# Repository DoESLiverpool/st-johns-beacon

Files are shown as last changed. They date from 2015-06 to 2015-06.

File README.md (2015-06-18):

A large scale 3D printable model of St John's Beacon (The Radio City Tower) in Liverpool. Intended to be printed on 
an Ultimaker 2 Extended, and take full advantage of the 30cm print height, to give a tower approximately 1m tall. 

Blank faced letter blocks around the circumfrence allow LEDs inside the cupola to light the letters for display from 
an Arduino inside.

 * DoES Liverpool's repo is at: [github.com/DoESLiverpool/st-johns-beacon](https://github.com/DoESLiverpool/st-johns-beacon)
 * Alternative git repo is at: [git.defproc.co.uk/DefProc/st-johns-beacon](https://git.defproc.co.uk/DefProc/st-johns-beacon)
 * Original CAD models are at [cad.onshape.com](https://cad.onshape.com/documents/28927cba45614a8eae7bdee6)

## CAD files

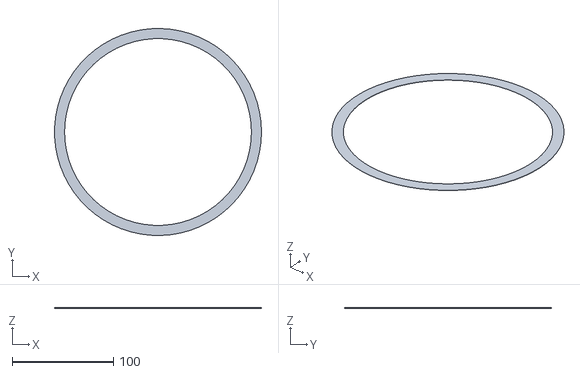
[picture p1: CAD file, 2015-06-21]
large-multi-piece/Letter Ring/RCT - Ring Pattern - bottom.stl
204.9 x 204.8 x 1.00

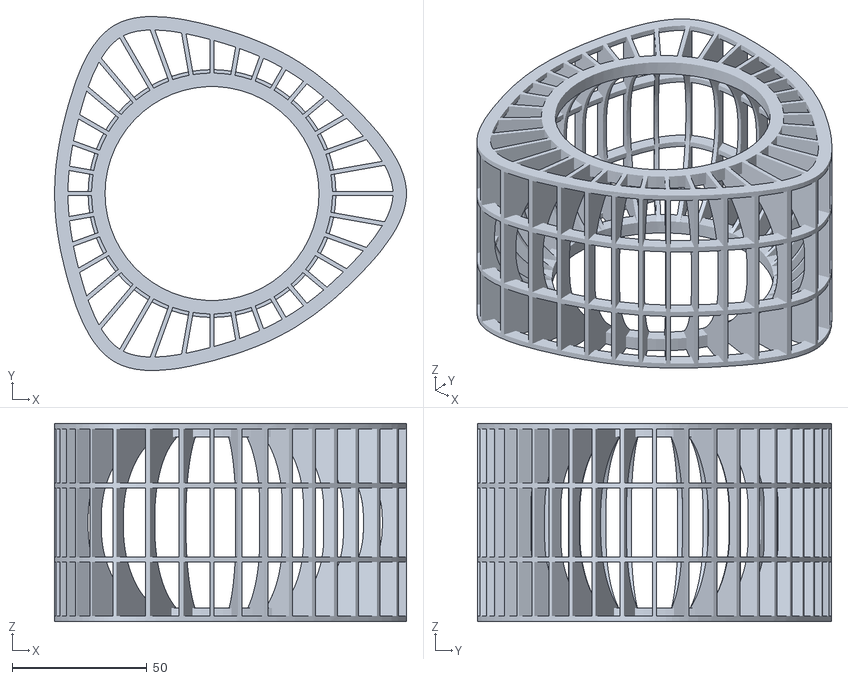
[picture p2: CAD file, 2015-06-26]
large-multi-piece/RCT - Advertising Hoarding.stl
130.7 x 131.4 x 73.5

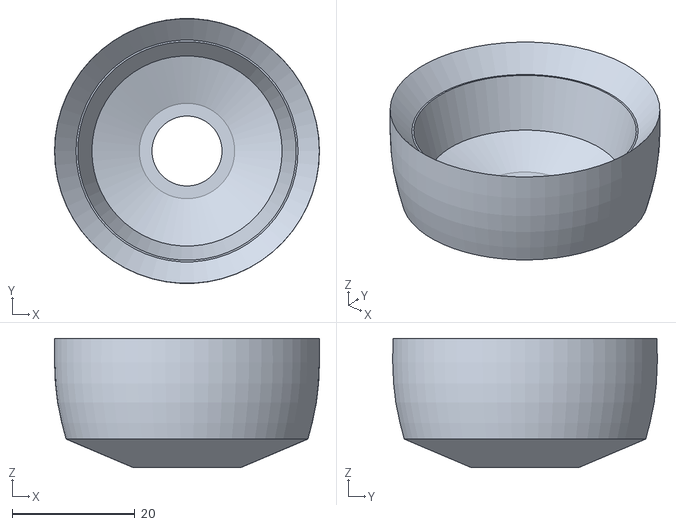
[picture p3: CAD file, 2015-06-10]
small-five-piece/St John's Beacon, Radio City Tower - Cupola.stl
43.1 x 43.1 x 21.0

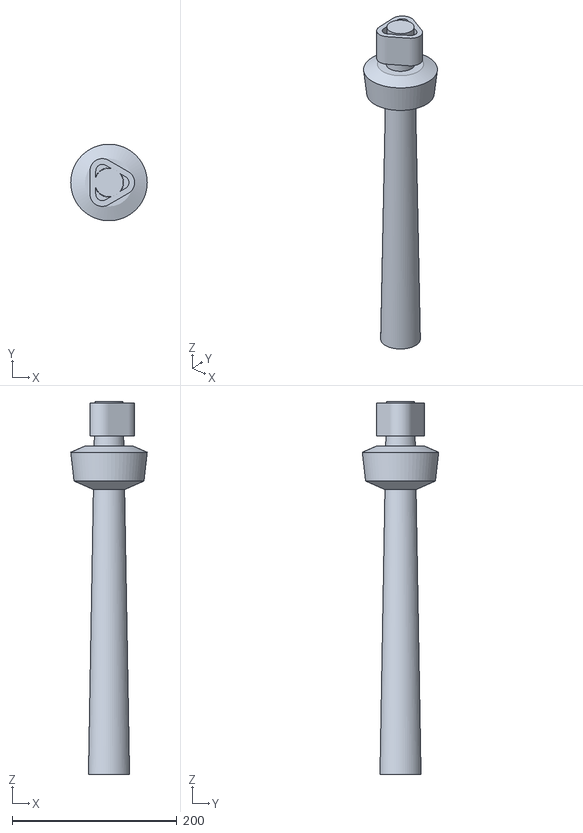
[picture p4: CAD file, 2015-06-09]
small-one-piece/St John's Beacon, Radio City Tower - Single Piece Tower.stl
93.0 x 92.9 x 453.0

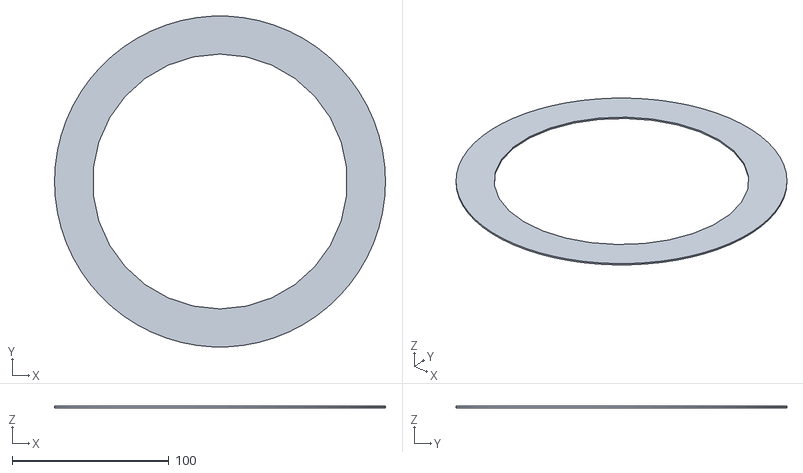
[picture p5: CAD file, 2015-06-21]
large-multi-piece/Letter Ring/RCT - Ring Pattern - top.stl
211.2 x 211.0 x 1.00

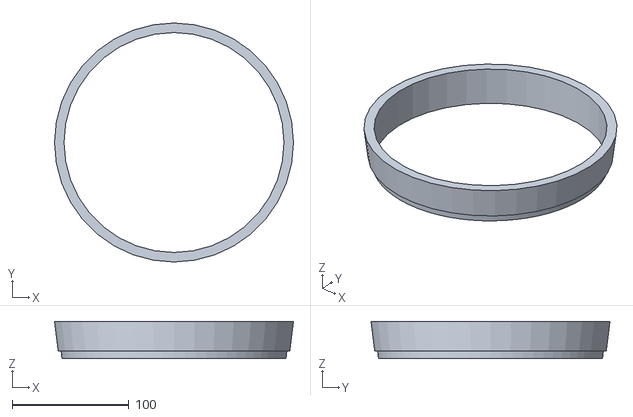
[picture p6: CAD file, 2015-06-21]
large-multi-piece/RCT - Bottom Windows.stl
205.1 x 205.1 x 32.0

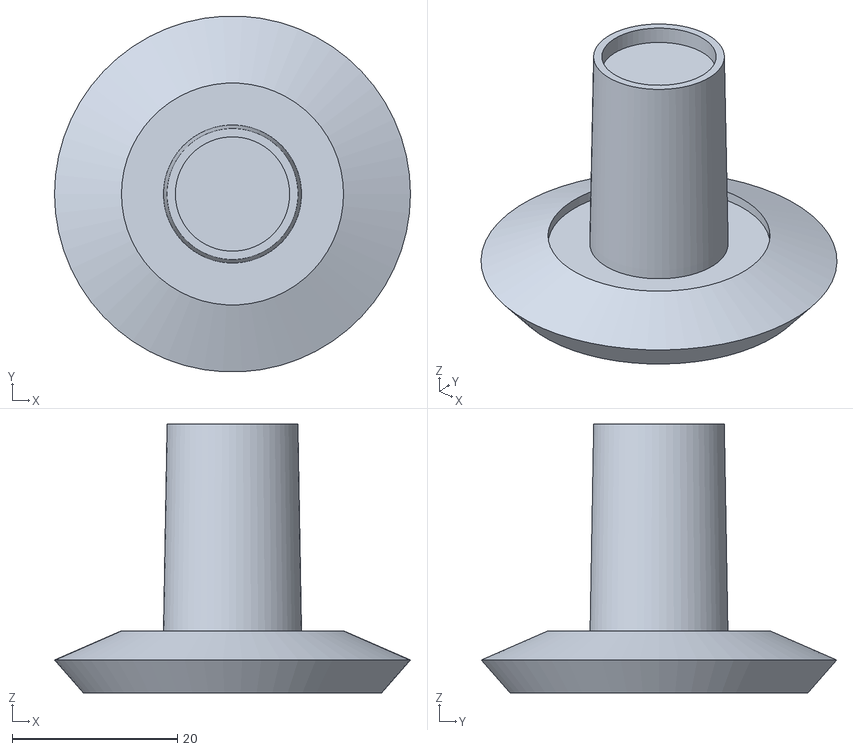
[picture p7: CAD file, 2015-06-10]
small-five-piece/St John's Beacon, Radio City Tower - Spire.stl
43.1 x 43.0 x 32.5

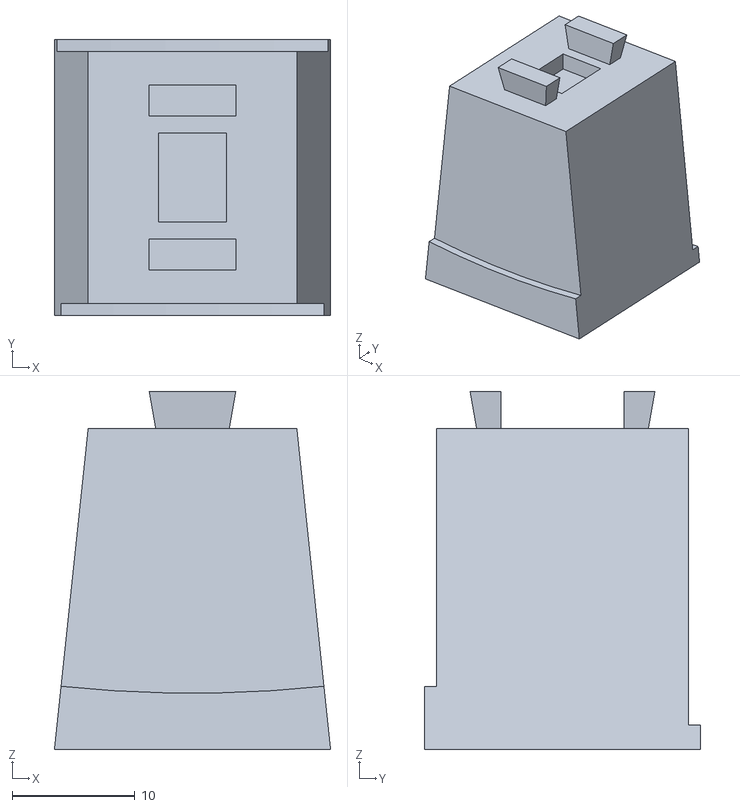
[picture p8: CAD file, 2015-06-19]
large-multi-piece/Letter Ring/RCT - Blank Letter Block.stl
22.5 x 22.5 x 29.2

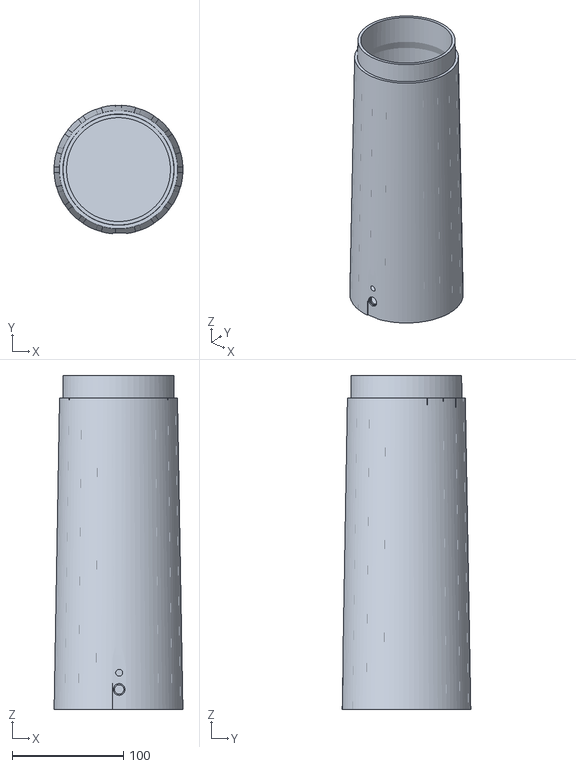
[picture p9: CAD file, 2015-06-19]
large-multi-piece/RCT - Tower Base 1.stl
115.7 x 115.5 x 300.0

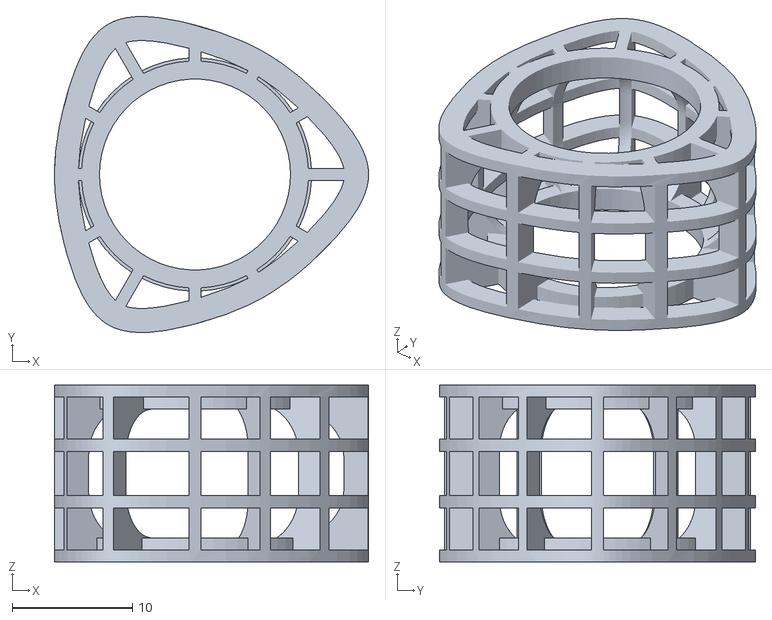
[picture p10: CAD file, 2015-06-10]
small-five-piece/St John's Beacon, Radio City Tower - Advertising Hoarding.stl
26.1 x 26.3 x 14.7

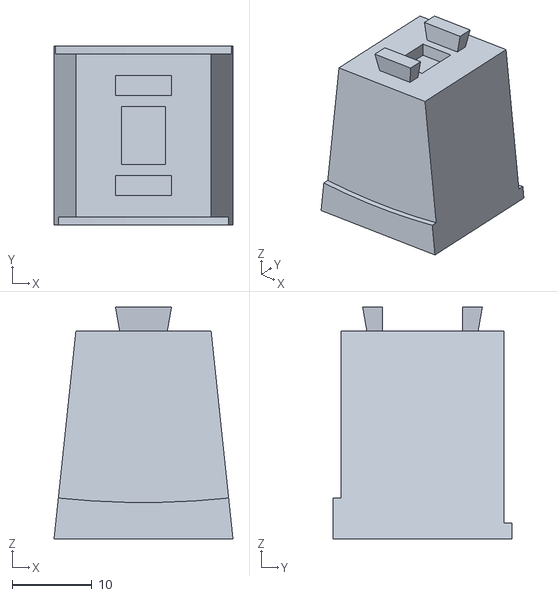
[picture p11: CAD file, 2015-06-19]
large-multi-piece/Letter Ring/letter-L.stl
22.5 x 22.5 x 29.2

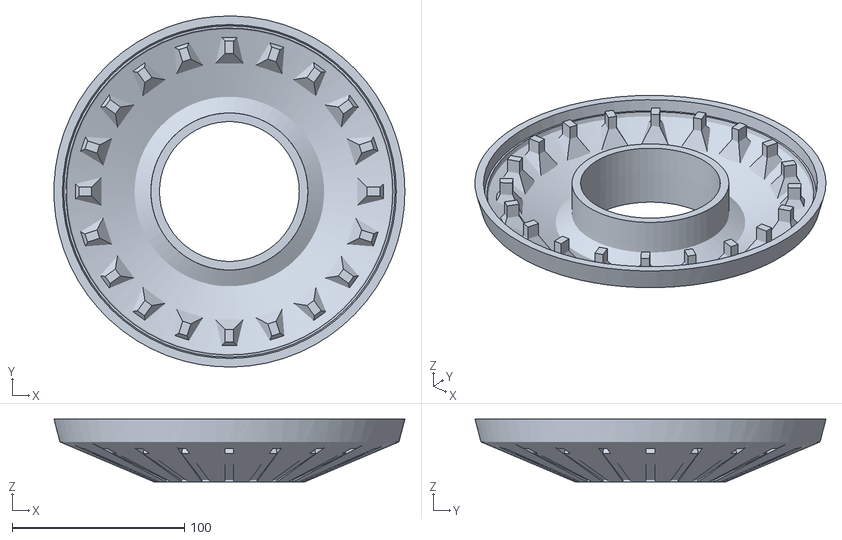
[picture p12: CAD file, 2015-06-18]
large-multi-piece/RCT - Cornice.stl
203.7 x 203.8 x 36.4

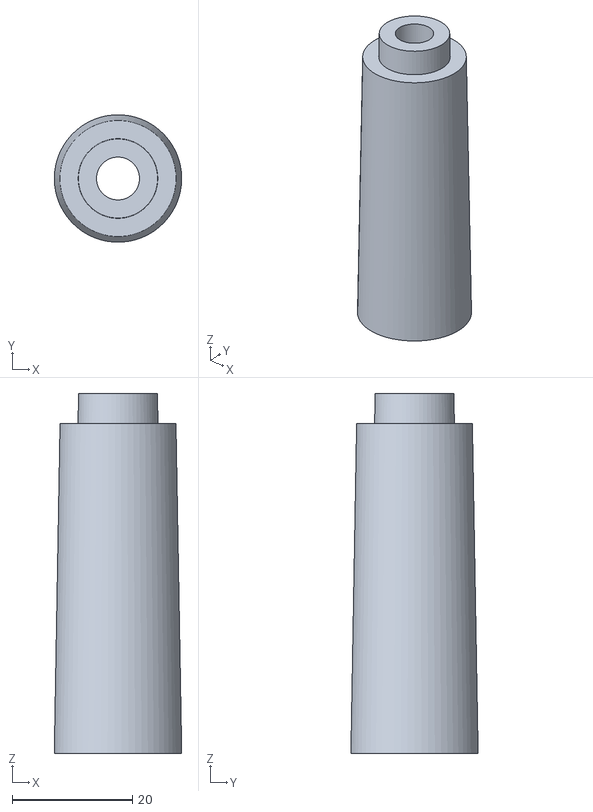
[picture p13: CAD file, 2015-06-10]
small-five-piece/St John's Beacon, Radio City Tower - Tower Base 2.stl
21.2 x 21.2 x 60.0

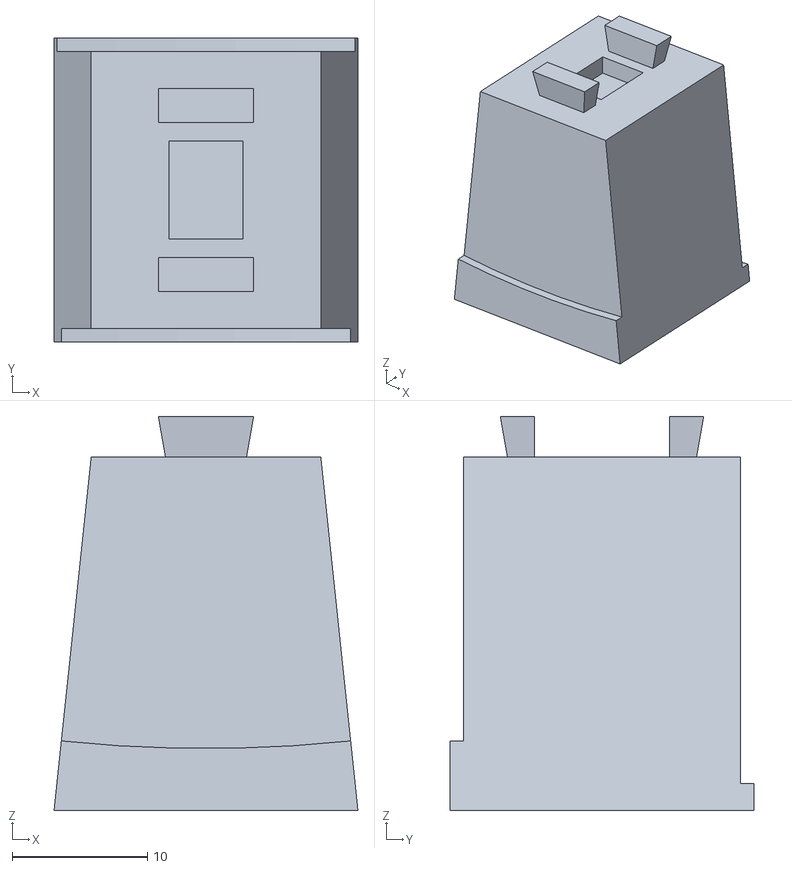
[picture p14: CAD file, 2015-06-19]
large-multi-piece/Letter Ring/letter-p.stl
22.5 x 22.5 x 29.2

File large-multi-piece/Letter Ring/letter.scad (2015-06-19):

letter="D";

difference() {
    import("RCT - Blank Letter Block.stl");
//    color("blue", 1) {
    translate([0,0,1.2]) {
        linear_extrude(height=6) {
            rotate([0,180,0]) {
                text(letter, size=18, font="Arial:style=Bold", valign="center", halign="center");
            }
        }
    }
    //}
}

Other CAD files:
large-multi-piece/RCT - Top Windows.stl
small-five-piece/St John's Beacon, Radio City Tower - Tower Base 1.stl
large-multi-piece/Letter Ring/letter-i.stl
large-multi-piece/RCT - Letter block ring.stl
large-multi-piece/Letter Ring/letter-D.stl
large-multi-piece/Letter Ring/letter-E.stl
large-multi-piece/Letter Ring/letter-S.stl
large-multi-piece/Letter Ring/letter-e.stl
large-multi-piece/Letter Ring/letter-l.stl
large-multi-piece/Letter Ring/letter-o.stl
large-multi-piece/Letter Ring/letter-r.stl
large-multi-piece/Letter Ring/letter-v.stl
large-multi-piece/RCT - Chimney.stl
large-multi-piece/RCT - Roof.stl
large-multi-piece/RCT - Tower Base 2.stl
large-multi-piece/RCT - Tower Base 3.stl
small-five-piece/St John's Beacon, Radio City Tower - Tower Base 3.stl

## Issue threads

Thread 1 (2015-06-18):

Print all the parts of the tower

DefProc, 2015-06-18:
- [x] Advertising Hoarding (silver)
   - [ ] Two replacement bars OR,
   - [ ] Print again.
 - [x] Chimney (white)
   - This is a little spotty in quality and would be better at a lower speed.
 - [x] Roof (white)
 - [x] Upper Windows (Transparent Blue)
 - [x] Letter Blocks (Smoked Black)
 - [x] Lower Windows (Transparent Blue)
 - [x] Cornice Floor (White)
 - [x] Tower Base 3 (White)
 - [x] Tower Base 2 (White)
 - [x] Tower Base 1 (White)

iambeano, 2015-06-18:
I can print the chimney as it will fit on my 3D printer and I have white ABS filament.

The other pieces that will fit are the advertising hoard and the letter blocks however, don't have the colours to match.

An alternative would be that I could print the whole hoard again but in black.

DefProc, 2015-06-18:
We have filament in 2.85mm PLA in the four colours. Will that fit your
printer?

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

iambeano, 2015-06-18:
Right now I've no idea! It's a CEL Robox- it can take third party filament, if I print a spool housing. I'll check it out and get back to you. But do you have spare transparent or smoke rolls for me to use over the weekend?

DefProc, 2015-06-18:
Ah, the specs say 1.75mm. Yes, it can take other filaments, but we only have 2.85mm PLA in these colours for the Ultimaker.

The long print time means having to be in DoES to change prints across the weekend though.

iambeano, 2015-06-18:
OK, thanks for looking it up- I'll at least do the chimney in white- I'll recheck the stock of filaments and make sure we can't do the hoarding in grey instead of smoke. Will get back to you tomorrow.

I could access does and set a print or two off if needed.

DefProc, 2015-06-19:
Cool, although if we're reprinting to chimney, it could do with a small hole in the top #2

Actually, it might do better with the "roof" as an insert in the chimney…

iambeano, 2015-06-19:
I'm in a conference today- if there's a heads up when the model is ready I'll get it printed.

iambeano, 2015-06-19:
Nope not got any grey- let me know if you don't mind the hoarding in black though.

iambeano, 2015-06-22:
Looking at your model, on saturday with @amcewen we agreed it might look odd- the abs I have will be a different shade of white and will look a tad strange.

But I could still do the hoarding in black if you like, @DefProc?

DefProc, 2015-06-26:
The advertising hoarding is being reprinted (as there's time)

The chimney and tower base parts could do with a reprint in the future, but it's good enough for a first outing.

Closed 2015-06-26.

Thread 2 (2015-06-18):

Fit an aerial to the tower using Ed's FM transmitter

cheapjack, 2015-06-18:
Add short range FM broadcasting facilty to the tower. To broadcast NERF noise and more... Use @cheapjack cardboard analogue radio for display

DefProc, 2015-06-18:
@amcewen suggested we could broadcast podcasts (maybe from Dan) as Radio
MakeFest.
On 18 Jun 2015 10:24, "Ross Dalziel @cheapjack" <notifications@github.com>
wrote:

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

amcewen, 2015-06-18:
I've pinged @MethodDan to see if he's up for it.  He's running podcasting courses all day at MakeFest, so I'm hoping that they'd end up collecting a bunch of mp3s or similar, which would be added to an SD card or similar (scp-ed over to a Raspberry Pi, so it'd run uninterrupted?) during the day and have Radio MakeFest just broadcast them in a loop.

MethodDan, 2015-06-18:
Hello chaps, I'm snowed under at the minute and I start a new job on Monday. If you're happy for me to just provide mp3s you can use then that's cool. On the day I'm doing workshops as you say but also running the crew with Les, fetching lunch for everyone in the van etc etc.

I can keep passing you mp3s as they are ready but doubt I can do the uploading and management of the streaming. If you're happy for me to just be an upstream contributor of audio files then I'm happy to do it.

We could also raid the Rathole Radio back catalogue for mp3's to get us going. I'm not sure how much we'll produce on the day of Makefest. Depends who turns up.

DefProc, 2015-06-18:
Just broadcasting from any available MP3 player should work surely?

Does it need a mount or hole for an external antenna on the top of the chimney piece?

DefProc, 2015-06-19:
@cheapjack @EdSaul what hole or connection or antenna mount should be added to the chimney piece?

epsaul, 2015-06-19:
@DefProc It would need a dipole of the size usually found on a car or FM radio. You could make one out of some coax cable and a metal coat-hanger. Or maybe a ferrite toroid balun to reduce size. I'll sort something out that's small and concealable.

DefProc, 2015-06-19:
What if we printed a hollow tower printed in a smaller scale in black to give the impression of the 10m mast on the top of the actual RCT (76mm high on the model)?

epsaul, 2015-06-19:
I can probably do it with an antenna 3" long of (say) 5mm diameter.

DefProc, 2015-06-19:
We have an FM transmitter that will fit in the chimney spire (tunecast II) that will need a stereo audio input in the base of the tower, or will need 12V power, and something inside the base to broadcast.

amcewen, 2015-06-24:
So, @MethodDan, would a Dropbox folder work for you to drop mp3s into?  I'm aiming to get the BeaconBot to pull things down from Dropbox, and then play them on a loop.

Is there any chance you could record a "This is Radio MakeFest" ident for us?  Then I can get it played in between each mp3 :-)

MethodDan, 2015-06-24:
Yeah I think that should work. It's easy enough to drop things into a dropbox folder. I have a feeling we might be challenged for bandwidth with that many geeks in one place but dropbox will just upload as soon as it can.

As for the ident thing, I can record something tonight. I'll use my best movie announcer voice. "This summer, comes the story of a Makefest...." :D

amcewen, 2015-06-25:
We have a script to do this now - checked in at https://github.com/brett-lempereur/beaconbot/commit/fa7d581c0d480077c46478e33b51fd30baaf5b3e.  @MethodDan, I'll share a dropbox folder with you to put the mp3s into, and if you manage to get an ident, we can configure the script to play it between tracks (the script does it, but only if there's an mp3 provided)

MethodDan, 2015-06-25:
OK sounds cool, I'll get an ident done but it might be tomorrow night now. If I give you the mp3 tomorrow night, hopefully that's early enough to load it on for Saturday :)

amcewen, 2015-06-25:
That's fine.  Just stick it in the Dropbox folder and tell me the filename.  It'll be a two minute job to enable it.  Thanks!

brett-lempereur, 2015-06-25:
I've got this running on the Pi that's hosting the bot now, it's pulling the files down from Dropbox every hour and playing the audio okay, everything launching at boot.

DefProc, 2015-06-26:
Although there's a mount for audio input at the base of the tower, I'd recommend that we actually place the FM transmitter outside the tower for this install.

amcewen, 2015-06-26:
@MethodDan suggested that RSS would work better, so have that up and running now.  It checks for new mp3s every 20 minutes.  Just need a URL for the MakeFest RSS feed from you now...

amcewen, 2015-06-28:
URL and ident received, and deployed.

Closed 2015-06-28.

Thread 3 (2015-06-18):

Create the Arduino program to flash the letter lights

DefProc, 2015-06-18:

brett-lempereur, 2015-06-18:
What sort of LEDs are you using?  I have some spare neopixel strip lying around if it'd be helpful.

DefProc, 2015-06-18:
@amcewen had a strip of [WS1606](http://www.adafruit.com/products/306) so I designed the [letter block ring](https://github.com/DoESLiverpool/st-johns-beacon/blob/master/large-multi-piece/RCT%20-%20Letter%20block%20ring.stl) with a 20mm pitch. The WS1606 has a much bigger pitch than this (~40mm?) but with the silicon sleeve stripped off, it folds nicely to 20mm and should clamp/glue in place. slicon

The older strip is a bit more limited (9 colours, and heavy processor use for PWM) and we can install it indefinitely. But I know the neopixels are much better.

What's the pitch like on the strip? (nothing's printed yet) And would you mind that we'll need to strip the weatherproof cover to fit them?

brett-lempereur, 2015-06-18:
Specification here, feel free to strip the cover, it'll never be used! Not sure if I have enough, but I can swing by tomorrow with what I have if its useful!

brett-lempereur, 2015-06-20:
I've made some progress with this.  The embedded lights can be controlled by sending a 24-bit RGB message to an MQTT broker.  Next step is to write a Twitter bot that when prompted will set the lights to the given colour, take a photo of the tower using a PiCamera, and tweet a response + photo -- any ideas/tips would be appreciated!

amcewen, 2015-06-20:
NodeRED could easily do the Twitter to MQTT and tweeting out at the end - the only bit you'd need to add would be the photo part.  If you can do that from the command-line that could also be done in NodeRED - maybe write a script that takes a photo and outputs its filename to stdout?  NodeRED would read in the stdout and then attach that picture (I think, haven't checked how you'd upload the photo to Twitter, or if it'd need tweaks to the NodeRED twitter node)

amcewen, 2015-06-20:
Having a quick poke round the NodeRED twitter node (http://flows.nodered.org/node/node-red-node-twitter) it seems that if you attach a javascript Buffer object as msg.media, then it'll get attached as an image, and there'll be ways to read a file into a Buffer...

Shout if you run at it in NodeRED and need any help...

brett-lempereur, 2015-06-20:
I've had a crack at this in Python (not much time, used what I know), and uploaded the code to https://github.com/brett-lempereur/beaconbot.  It's totally untested (haven't even run it), will have another look tomorrow and can hack the remaining bits together at Maker Night!

DefProc, 2015-06-21:
I didn't realise that you weren't in the members list for the DoES
Liverpool organisation on github. You have an invite now, so you should
be able to push to this repo.

If you'd rather it beaconbot stay in it's own repo, cool. When you're
ready, I'll submodule it from this one.

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

brett-lempereur, 2015-06-22:
Cheers, after hacking and fixing it tonight (and not including my credentials in the commit) I'll put it into this repository!

brett-lempereur, 2015-06-23:
Okay, this is now done, see http://twitter.com/doestower.  The bot code and everything is up at https://github.com/brett-lempereur/beaconbot, the JSON file in the root is the Node-Red workspace.  Submodule away!

I've added you and adrian as collaborators on it, so please start adding messages and responses to the JSON resources -- I'm running out of ideas and its already a little repetitive.  It's pulling down its configuration from the GitHub repository when it starts up.

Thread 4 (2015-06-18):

Create the small holes on the side of the tower (maybe?)

DefProc, 2015-06-18:
There are some small holes running vertically in a pattern up some sides of the tower that we could add to the model for greater accuracy.

DefProc, 2015-06-22:
I'm gonna skip these, so the modelling is now effectively complete.

Closed 2015-06-22.

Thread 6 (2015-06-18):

Add manual support areas for the cornice holes

DefProc, 2015-06-18:
The square light holes facing downwards will need to be supported for printing, so the edges don't collapse. Adding manual supports will reduce the print time compared to automatic support material.

DefProc, 2015-06-18:
Added 81dfad85

Closed 2015-06-18.

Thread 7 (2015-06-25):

camera mount for beaconbot

brett-lempereur, 2015-06-25:
It would be great to have some way of mounting the camera to point directly at the tower from the Raspberry Pi.

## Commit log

2015-06-09 inital commit of STLs
    [St John's Beacon, Radio City Tower - Advertising Hoarding.stl, St John's Beacon, Radio City Tower - Cupola.stl, St John's Beacon, Radio City Tower - Single Pie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]
2015-06-10 3mm wall 5-piece for testing at 20% scale
    [St John's Beacon, Radio City Tower - Advertising Hoarding.stl, St John's Beacon, Radio City Tower - Cupola.stl, St John's Beacon, Radio City Tower - Spire.stl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]
2015-06-10 revisions to large (3mm wall, lattice hoarding)
    [St John's Beacon, Radio City Tower - Advertising Hoarding.stl, St John's Beacon, Radio City Tower - Cupola.stl, St John's Beacon, Radio City Tower - Spire.stl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]
2015-06-10 spreadsheet of the time and material reqs. for the large tower
    [material-time-requirements.ods]
2015-06-12 updated hoarding print time
    [material-time-requirements.ods]
2015-06-15 split roof and spire, removed windows from cupola and added lower striping
    [St John's Beacon, Radio City Tower - Chimney.stl, St John's Beacon, Radio City Tower - Cupola.stl, St John's Beacon, Radio City Tower - Roof.stl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]
2015-06-15 added 8.2mm DC jack hole in the base
    [St John's Beacon, Radio City Tower - Tower Base 1.stl]
2015-06-17 spreadsheet is out of date
    [material-time-requirements.ods]
2015-06-17 renamed folders so they make more sense
    [St John's Beacon, Radio City Tower - Advertising Hoarding.stl, St John's Beacon, Radio City Tower - Chimney.stl, St John's Beacon, Radio City Tower - Cupola.st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]
2015-06-17 included blank letter block and an stl to operate on it
    [RCT-Blank-Letter-Block.stl, letter.scad]
2015-06-17 transformed letter block to line up with x-y plane and origin
    [RCT-Blank-Letter-Block.stl]
2015-06-18 renamed Cupola to Cornice
    [St John's Beacon, Radio City Tower - Cornice.stl]
2015-06-18 added top windows for printing
    [St John's Beacon, Radio City Tower - Top Windows.stl]
2015-06-18 renamed file prefix to RCT
    [RCT - Advertising Hoarding.stl, RCT - Chimney.stl, RCT - Cornice.stl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]
2015-06-18 initial (blank) letter block ring
    [RCT - Letter block ring.stl]
2015-06-18 added manual, breakoff, hole support for the downlights
    [RCT - Cornice.stl]
2015-06-19 changed the blank letter stl name to match the onshape model
    [RCT - Blank Letter Block.stl, RCT-Blank-Letter-Block.stl]
2015-06-19 removed letter from blank using openscad
    [RCT - Blank Letter Block.stl, letter.scad]
2015-06-19 revised letter block to hollow, auto generate script and built all unique letters
    [RCT - Blank Letter Block.stl, letter-D.stl, letter-E.stl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]
2015-06-19 resized the letter blocks for neopixel strip @ 17mm pitch
    [RCT - Blank Letter Block.stl, letter-D.stl, letter-E.stl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]
2015-06-19 added audio jack hole to tower base 1
    [RCT - Tower Base 1.stl]
2015-06-21 added bottom windows STL
    [RCT - Bottom Windows.stl]
2015-06-21 rings to help lining up the letter blocks for gluing
    [RCT - Ring Pattern - bottom.stl, RCT - Ring Pattern - top.stl]
2015-06-21 new guide ring for gluing the letter blocks into a ring
    [RCT - Ring Pattern - bottom.stl]
2015-06-26 changed hoarding uprights from 2mm to 1.6mm to prevent fill
    [RCT - Advertising Hoarding.stl]
